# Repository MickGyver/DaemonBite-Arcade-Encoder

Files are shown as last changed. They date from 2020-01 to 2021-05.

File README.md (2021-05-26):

# DaemonBite-Arcade-Encoder
This is an arcade controller project for the MiSTer FPGA project and any other device accepting USB HID joysticks using an Arduino Pro Micro. This project can also be used to create a NeoGeo/Atari/Commodore/Amiga controller to USB adapters.

This project is an open source "lite" version of an arcade encoder I sell in my shop. If you want to support my work I sell the fully featured ones at https://daemonbite.com.

The input lag for an arcade controller or adapter built around this project is minimal. Here is the result from a test with a 1ms polling rate on a MiSTer with this project:

| Samples | Average | Max | Min | Std Dev |
| --- | --- | --- | --- | --- |
| 13962 | 0.74ms | 1.28ms | 0.23ms | 0.29ms |

## Wiring (Arcade Controller)
The wiring is simple. Connect one leg of each microswitch to GND and the other leg to the digital pin according to the schematic below. That's it!  
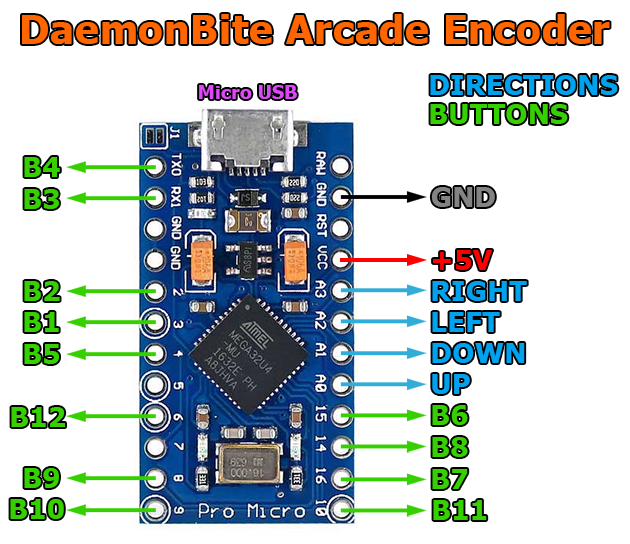
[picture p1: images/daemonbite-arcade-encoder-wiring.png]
Assemble1


## Recommended layout (for PS3 stick compatibility)
Blue text in image (silk screen) corresponds to the Bx button numbers in the image for wiring above. 
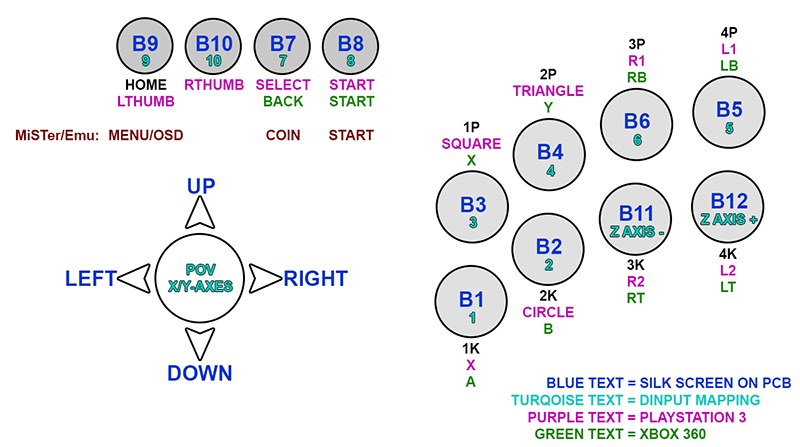
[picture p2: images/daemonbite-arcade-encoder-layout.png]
Assemble2


## Wiring (NeoGeo USB Adapter)
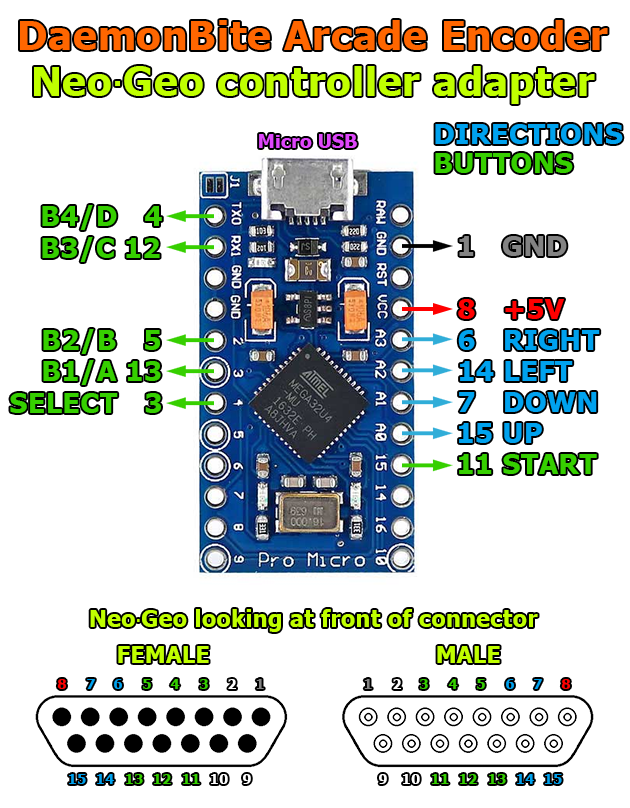
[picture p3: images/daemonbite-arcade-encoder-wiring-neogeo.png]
Assemble3


## Wiring (Atari/Commodore/Amiga USB Adapter)
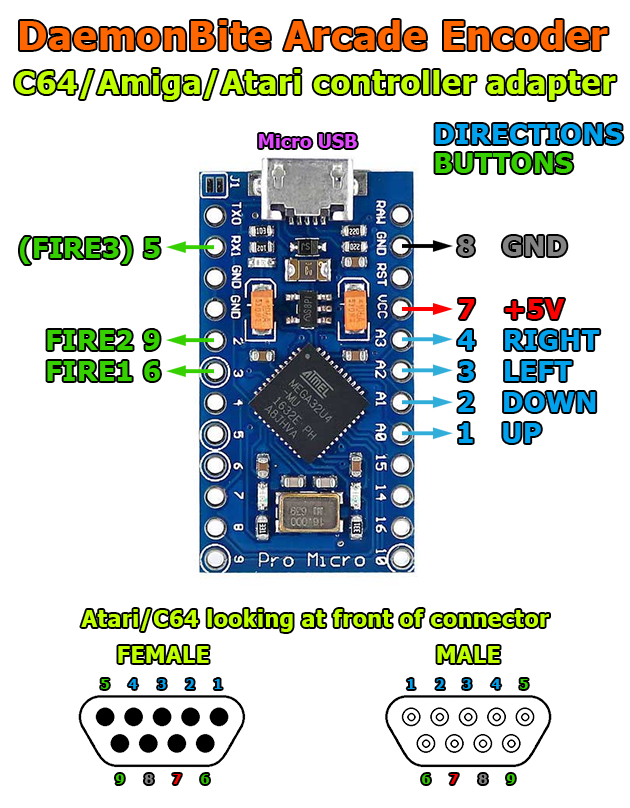
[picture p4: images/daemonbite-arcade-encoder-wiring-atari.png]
Assemble4


## Programming the Arduino
1. Download the free Arduino IDE: https://www.arduino.cc/en/main/software
2. Connect the Arduino Pro Micro to a USB port and let the drivers install.
3. Choose the correct board and virtual COM port in the IDE.
3. Compile/Upload the project.

## License
This project is licensed under the GNU General Public License v3.0. The name "daemonbite" is registered to my company in Finland and should not be used by others.

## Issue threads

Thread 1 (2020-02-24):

Support for multi-platform/universal wiring

mgolfieri, 2020-02-24:
It would be great to be able use the same platform wiring for all. Say you have the Arcade wiring, you can switch to control an Amiga or NeoGeo with the same setup, just by switching mapping in SW.  At the end of the day, GND and +V are going to be in the same spot, everything else should be doable as pure signals?

sorgelig, 2020-02-25:
From my point of view it's better to stick to the same adapter without jumping between different ones. Arduino Micro is dirt cheap, so just buy several boards and make adapters specific to different controllers and then update the FW only within the same adapter.
The project is targeted to simpliest way to build with minimum additional components. And this is a big advantage over universal adapters adjusting their pins to different controllers and require more complex wiring or even additional board.

MickGyver, 2020-02-26:
I agree with Sorgelig. Marcello, the adapters will work for various cores without rewiring anything, you can map the controller for each core in the menu on the MiSTer any way you want.

mgolfieri, 2020-02-26:
thank you both, makes sense.  Closing!

Closed 2020-02-26.

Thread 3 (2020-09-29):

Error compiling downloaded code

leeyanhuilyh, 2020-09-29:
Hi there. First of all, thank you for creating this project. My issue is that I am not able to compile the code. There are a lot of error messages here, so I think I might be missing some libraries. Here are the error messages:

In file included from C:\Users\metal\Desktop\DaemonBite-Arcade-Encoder\DaemonBiteArcadeEncoder\DaemonBiteArcadeEncoder.ino:24:0:
Gamepad.h:43:1: error: expected class-name before '{' token
 {
 ^
Gamepad.h:49:23: error: 'USBSetup' has not been declared
     int getDescriptor(USBSetup& setup);
                       ^~~~~~~~
Gamepad.h:51:16: error: 'USBSetup' has not been declared
     bool setup(USBSetup& setup);
                ^~~~~~~~
C:\Users\metal\Desktop\DaemonBite-Arcade-Encoder\DaemonBiteArcadeEncoder\DaemonBiteArcadeEncoder.ino: In function 'void setup()':
DaemonBiteArcadeEncoder:71:3: error: 'DDRF' was not declared in this scope
   DDRF  &= ~B11110000; // Set A0-A3 as inputs
   ^~~~
C:\Users\metal\Desktop\DaemonBite-Arcade-Encoder\DaemonBiteArcadeEncoder\DaemonBiteArcadeEncoder.ino:71:3: note: suggested alternative: 'WDRF'
   DDRF  &= ~B11110000; // Set A0-A3 as inputs
   ^~~~
   WDRF
DaemonBiteArcadeEncoder:72:3: error: 'PORTF' was not declared in this scope
   PORTF |=  B11110000; // Enable internal pull-up resistors
   ^~~~~
C:\Users\metal\Desktop\DaemonBite-Arcade-Encoder\DaemonBiteArcadeEncoder\DaemonBiteArcadeEncoder.ino:72:3: note: suggested alternative: 'PORT0'
   PORTF |=  B11110000; // Enable internal pull-up resistors
   ^~~~~
   PORT0
DaemonBiteArcadeEncoder:81:3: error: 'DDRE' was not declared in this scope
   DDRE  &= ~B01000000; // Pin 7 as input
   ^~~~
C:\Users\metal\Desktop\DaemonBite-Arcade-Encoder\DaemonBiteArcadeEncoder\DaemonBiteArcadeEncoder.ino:81:3: note: suggested alternative: 'DDRB'
   DDRE  &= ~B01000000; // Pin 7 as input
   ^~~~
   DDRB
DaemonBiteArcadeEncoder:82:3: error: 'PORTE' was not declared in this scope
   PORTE |=  B01000000; // Enable internal pull-up resistor
   ^~~~~
C:\Users\metal\Desktop\DaemonBite-Arcade-Encoder\DaemonBiteArcadeEncoder\DaemonBiteArcadeEncoder.ino:82:3: note: suggested alternative: 'PORT0'
   PORTE |=  B01000000; // Enable internal pull-up resistor
   ^~~~~
   PORT0
C:\Users\metal\Desktop\DaemonBite-Arcade-Encoder\DaemonBiteArcadeEncoder\DaemonBiteArcadeEncoder.ino: In function 'void loop()':
DaemonBiteArcadeEncoder:108:20: error: 'PINF' was not declared in this scope
     axesDirect = ~(PINF & B11110000);
                    ^~~~
In file included from sketch\Gamepad.cpp:26:0:
Gamepad.h:43:1: error: expected class-name before '{' token
 {
 ^
Gamepad.h:49:23: error: 'USBSetup' has not been declared
     int getDescriptor(USBSetup& setup);
                       ^~~~~~~~
C:\Users\metal\Desktop\DaemonBite-Arcade-Encoder\DaemonBiteArcadeEncoder\DaemonBiteArcadeEncoder.ino:108:20: note: suggested alternative: 'PIN0'
     axesDirect = ~(PINF & B11110000);
                    ^~~~
                    PIN0
Gamepad.h:51:16: error: 'USBSetup' has not been declared
     bool setup(USBSetup& setup);
                ^~~~~~~~
sketch\Gamepad.cpp: In constructor 'Gamepad_::Gamepad_()':
Gamepad.cpp:75:28: error: class 'Gamepad_' does not have any field named 'PluggableUSBModule'
 Gamepad_::Gamepad_(void) : PluggableUSBModule(1, 1, epType), protocol(HID_REPORT_PROTOCOL), idle(1)
                            ^~~~~~~~~~~~~~~~~~
Gamepad.cpp:75:71: error: 'HID_REPORT_PROTOCOL' was not declared in this scope
 Gamepad_::Gamepad_(void) : PluggableUSBModule(1, 1, epType), protocol(HID_REPORT_PROTOCOL), idle(1)
                                                                       ^~~~~~~~~~~~~~~~~~~
Gamepad.cpp:77:15: error: 'EP_TYPE_INTERRUPT_IN' was not declared in this scope
   epType[0] = EP_TYPE_INTERRUPT_IN;
               ^~~~~~~~~~~~~~~~~~~~
sketch\Gamepad.cpp:77:15: note: suggested alternative: 'EMPTY_INTERRUPT'
   epType[0] = EP_TYPE_INTERRUPT_IN;
               ^~~~~~~~~~~~~~~~~~~~
               EMPTY_INTERRUPT
Gamepad.cpp:78:3: error: 'PluggableUSB' was not declared in this scope
   PluggableUSB().plug(this);
   ^~~~~~~~~~~~
sketch\Gamepad.cpp: In member function 'int Gamepad_::getInterface(uint8_t*)':
Gamepad.cpp:84:3: error: 'HIDDescriptor' was not declared in this scope
   HIDDescriptor hidInterface = {
   ^~~~~~~~~~~~~
sketch\Gamepad.cpp:84:3: note: suggested alternative: 'getDescriptor'
   HIDDescriptor hidInterface = {
   ^~~~~~~~~~~~~
   getDescriptor
Gamepad.cpp:89:30: error: 'hidInterface' was not declared in this scope
   return USB_SendControl(0, &hidInterface, sizeof(hidInterface));
                              ^~~~~~~~~~~~
sketch\Gamepad.cpp:89:30: note: suggested alternative: 'getInterface'
   return USB_SendControl(0, &hidInterface, sizeof(hidInterface));
                              ^~~~~~~~~~~~
                              getInterface
Gamepad.cpp:89:10: error: 'USB_SendControl' was not declared in this scope
   return USB_SendControl(0, &hidInterface, sizeof(hidInterface));
          ^~~~~~~~~~~~~~~
sketch\Gamepad.cpp: At global scope:
Gamepad.cpp:92:29: error: 'int Gamepad_::getDescriptor' is not a static data member of 'class Gamepad_'
 int Gamepad_::getDescriptor(USBSetup& setup)
                             ^~~~~~~~
Gamepad.cpp:92:29: error: 'USBSetup' was not declared in this scope
sketch\Gamepad.cpp:92:29: note: suggested alternative: 'setup'
 int Gamepad_::getDescriptor(USBSetup& setup)
                             ^~~~~~~~
                             setup
Gamepad.cpp:108:22: error: 'bool Gamepad_::setup' is not a static data member of 'class Gamepad_'
 bool Gamepad_::setup(USBSetup& setup)
                      ^~~~~~~~
Gamepad.cpp:108:22: error: 'USBSetup' was not declared in this scope
sketch\Gamepad.cpp:108:22: note: suggested alternative: 'setup'
 bool Gamepad_::setup(USBSetup& setup)
                      ^~~~~~~~
                      setup
sketch\Gamepad.cpp: In member function 'void Gamepad_::send()':
Gamepad.cpp:159:12: error: 'pluggedEndpoint' was not declared in this scope
   USB_Send(pluggedEndpoint | TRANSFER_RELEASE, &_GamepadReport, sizeof(GamepadReport));
            ^~~~~~~~~~~~~~~
Gamepad.cpp:159:30: error: 'TRANSFER_RELEASE' was not declared in this scope
   USB_Send(pluggedEndpoint | TRANSFER_RELEASE, &_GamepadReport, sizeof(GamepadReport));
                              ^~~~~~~~~~~~~~~~
sketch\Gamepad.cpp:159:30: note: suggested alternative: '__ATOMIC_RELEASE'
   USB_Send(pluggedEndpoint | TRANSFER_RELEASE, &_GamepadReport, sizeof(GamepadReport));
                              ^~~~~~~~~~~~~~~~
                              __ATOMIC_RELEASE
Gamepad.cpp:159:3: error: 'USB_Send' was not declared in this scope
   USB_Send(pluggedEndpoint | TRANSFER_RELEASE, &_GamepadReport, sizeof(GamepadReport));
   ^~~~~~~~
sketch\Gamepad.cpp:159:3: note: suggested alternative: 'USBS0'
   USB_Send(pluggedEndpoint | TRANSFER_RELEASE, &_GamepadReport, sizeof(GamepadReport));
   ^~~~~~~~
   USBS0
sketch\Gamepad.cpp: In member function 'uint8_t Gamepad_::getShortName(char*)':
Gamepad.cpp:164:7: error: 'next' was not declared in this scope
   if(!next)
       ^~~~
sketch\Gamepad.cpp:164:7: note: suggested alternative: 'exit'
   if(!next)
       ^~~~
       exit
exit status 1
expected class-name before '{' token

Could someone shed some light on this issue?
Thanks.

vcoraba, 2020-11-14:
I had same problem but I could compile selecting Arduino Leonardo Instead arduino mini Pro. Good luck

0x15e, 2020-11-18:
The naming for the board this uses is really tricky. It's meant to be used with the "Arduino Pro Micro", which is a board made by Sparkfun ([this board](https://deskthority.net/wiki/Arduino_Pro_Micro)).

Unfortunately, over the years, there's also been about 100 other combinations of Arduino names including words like "pro," "mini," "micro," etc. so it gets really hard to tell the things apart. As you found, selecting the Leonardo gets the job done. I suspect that installing [Sparkfun's board files](https://github.com/sparkfun/Arduino_Boards) would probably get you the proper name for it in the list too, if that was important to you.

I remember being a little confused by this back when I put my adapters together as well. @MickGyver would it be possible to clarify the programming documentation a little? I think just some extra notes in the "Programming the Arduino" section would be enough. Just explain which board should be used and what it might be called in the IDE. I could probably do a PR for this but it might take a while before I can get around to it.

leeyanhuilyh, 2020-12-30:
Sorry for the late update. You guys are right, it should be compiled with Arduino Leonardo. Closing this issue. Thanks for your help!

Closed 2020-12-30.

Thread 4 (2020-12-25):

Changing the digital pin in case the board doesn't have enough

Gildedboy, 2020-12-25:
right now im trying to use the program and so far so good

sadly my arduino board (it's a Leonardo sold by a local electronic company) only have 13 digital pins instead of 16, so I'm unable to map out buttons B6-B7-B8, it is possible to change it so I can use another available pins?

the pin layout it's similar to this
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

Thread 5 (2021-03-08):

In emulationstation problem

Luciano2018, 2021-03-08:
Hi, thanks for this great code, is really fast, have a problem with the joystick, mine have switches instead of potenciometers, this maybe, cause that when choose console or game, step 4 consoles or games only pressing once the joystick, in the game works great, but can figureout how to fix it, try ps3 and neogeo option, the same issue

0x15e, 2021-03-08:
I had a similar problem with my build. Try looking in the source for the place where debounce is configured and enable it. That took care of my problem and didn't add any discernable lag.

Luciano2018, 2021-03-08:
Thanks for the quick help, i try your solution, hope too works🙏 cause the code its amazing.

Luciano2018, 2021-03-08:
Thank so much!!! Hours try different things and the answer already there hehe . For someone else with this Not an Issue, the simple solution is, in the sketch(DaemonBiteArcadeEncoder.ino), just change this line:
#define DEBOUNCE 0
to
#define DEBOUNCE 1

compile and upload just that, thanks again for the really fast help. Now i can play without lags and perfect in a pi 4, with pi os in retropie 4.7.9. Thanks!

juri74, 2021-04-01:
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

thanks but this will add 10ms of lag!

Luciano2018, 2021-04-01:
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

I dont have tools for measure delay, in real life isn't difference Jury, is working perfectly my joystick, i push all buttons without delay, and in the readme page of this code say that delay is max 1.28ms . I dont notice any change when change debounce to 1 , if in laboratory the delay change to 10ms i couldn't see any difference. By the way, zero delay board have 15ms of delay, so equally we have -5ms of delay with this code. In my particular case, i can play games with debounce 0, but in the menu emulationstation all go wrong, like if we push Re Pág in a text processor(the behaviour). So if you want the minimum delay posible(readme) just use the code like it is, with debounce 0, and navigate emulationstation with a keyboard or ir control, but if you want manage with your diy joystick at emulationstation then put debounce 1, is just a choice, in both case no visible delay in real world, if you notice it, maybe check your solder joints with a tester, checking a correct continuity, and dont put large cable, just the correct large for make the solder. You can see my tutorial with my diy joystick with this cool code if you google my name "Luciano Rabassa". Give it a try to this code, MickGyver make a great work!!!

MickGyver, 2021-04-01:
The debounce function will only add about 32µs of lag, not 10ms.
/MickGyver    On Thursday, April 1, 2021, 05:31:30 PM GMT+3, Raspberry Pi Buenos Aires ***@***.***> wrote:

Thank so much!!! Hours try different things and the answer already there hehe . For someone else with this Not an Issue, the simple solution is, in the sketch(DaemonBiteArcadeEncoder.ino), just change this line:
#define DEBOUNCE 0
to
#define DEBOUNCE 1
compile and upload just that, thanks again for the really fast help. Now i can play without lags and perfect in a pi 4, with pi os in retropie 4.7.9. Thanks!

thanks but this will add 10ms of lag!

I dont have tools for measure delay, in real life isn't difference Jury, is working perfectly my joystick, i push all buttons without delay, and in the readme page of this code say that delay is max 1.28ms . I dont notice any change when change debounce to 1 , if in laboratory the delay change to 10ms i couldn't see any difference. By the way, zero delay board have 15ms of delay, so equally we have -5ms of delay with this code. In my particular case, i can play games with debounce 0, but in the menu emulationstation all go wrong, like if we push Re Pág in a text processor(the behaviour). So if you want the minimum delay posible(readme) just use the code like it is, with debounce 0, and navigate emulationstation with a keyboard or ir control, but if you want manage with your diy joystick at emulationstation then put debounce 1, is just a choice, in both case no visible delay in real world, if you notice it, maybe check your solder joints with a tester, checking a correct continuity, and dont put large cable, just the correct large for make the solder. You can see my tutorial with my diy joystick with this cool code if you google my name "Luciano Rabassa". Give it a try to this code, MickGyver make a great work!!!

—
You are receiving this because you are subscribed to this thread.
Reply to this email directly, view it on GitHub, or unsubscribe.

Luciano2018, 2021-04-01:
Thanks for the real tech answer your code rocks 😎 Really thanks 👏👏👏

juri74, 2021-04-03:
Thank you! i read the 10ms on the code, 32µs is nothing :)

Closed 2021-03-08.

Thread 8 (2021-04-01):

Feature request

juri74, 2021-04-01:
Please, is it possible to use a standard arduino leonardo board, with the ability to use all available inputs?
So we could have 2 player controls, each one with 6 buttons + 3 other buttons (coin, 1p start and 2p start)
according to this sheet there are sufficient pins.
https://i.pinimg.com/originals/ac/cf/bb/accfbb18d1cea83169181a032a02b605.png
thanks

0x15e, 2021-04-01:
It has a 32u4 mcu so it should work fine (especially considering that when you program a pro micro, you still select Leonardo as the board type).

It should just be a matter of figuring out how the pins map, if they're even different at all. That should be easy enough to figure out by programming it and use some jumper wires to test which pins activate which functions. Start by using the same numbered pins as they're labeled in the diagram and if they don't match up, move on from there.

juri74, 2021-04-03:
too hard to do for my little knowledge :D
thank you anyway :)

kparlin, 2021-04-05:
Just spit balling here, but couldn't you wire two boards and assign player 1 to one and player 2 to the other? I have not tried it yet.

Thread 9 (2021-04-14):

Issues with old Neo Geo stick

0x15e, 2021-04-14:
I built one of these to use with my Neo Geo controllers (some CD pads as well as an old-style home stick).

It works beautifully with the CD pads but there's something really weird going on with the stick.

On the stick, if I hold Start long enough, it triggers Select as well (or maybe it's Select triggering Start, I don't have it in front of me right now). It also happens if I rapidly press the button enough times. It's like the presses have a cumulative effect (which makes no sense because all the buttons do is short a pin to ground in the old home sticks.

Holding the other button doesn't have the same effect and all other directions and buttons are working properly, and like I said, the CD pads work perfectly.

Is there something known weird about the old sticks? Or could there be a way to modify my stick to make it more reliable (decoupling caps, a buffer, etc.)? It's not like I go around holding the Start (or Select) button but it would be nice to not have to worry about accidentally triggering the MiSTer or Universe Bios menus.

Closed 2021-04-28.

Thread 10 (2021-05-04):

"menu ok" action : impossible to assign

robinmasters2, 2021-05-04:
hello,
I've just setup an arduino pro micro and loaded it with the arcade encoder software.
I use it on mister.

The issue I'm having  is that, when assigning the buttons for the mister menu, a double clic is happening when assigning the "menu ok" action. in consequence It also assigns the "menu back" action on the same button.

it's only happening is this particular situation.
in game no double click.
it happens whathever the button is.

after sharing with friends, looks like two of my pals are expériencing the same issue.
is there already a workaround ?

thank you.

0x15e, 2021-05-05:
You need to enable debounce in the source and reflash your Arduino. It should be as simple as uncommenting one line.

robinmasters2, 2021-05-05:
thank you it worked !

Closed 2021-05-05.

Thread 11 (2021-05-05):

How do you measure input delay?

nebhead, 2021-05-05:
Not an issue, just curious how you are measuring input delay on this project.  I'd put together my own arcade stick example a couple of years back ([link to the commit here](https://github.com/nebhead/ArduinoJoystickLibrary/commit/2263e785853077b965f86cb6ac096e8d8c8b6f31)) as a fork of someone else's project and I'd like to know how well it works compared to this one.  Yours looks much cleaner and I may consider switching over.  (also, expect some traffic here as someone has posted a video using your project to Reddit - consider setting up discussions on this repository)  Nice work!

0x15e, 2021-05-05:
I'm 99% sure he's using Porkshop's MiSTer latency tester core / procedure. You can find more info about the procedure and aggregated results here (check all the different sheets for the results): https://docs.google.com/spreadsheets/d/1KlRObr3Be4zLch7Zyqg6qCJzGuhyGmXaOIUrpfncXIM/edit#gid=369482991

I tried some other Arduino / STM32 firmwares (including Freejoy but not sure if I tried the one you linked) and DaemonBite was so much faster than everything it wasn't even funny.

Especially impressive is the way debounce is implemented. Without debounce, many arcade controls such as the IL Eurostick and Happ buttons will trigger multiple times per activation so you really need it in the arcade adapter. When I tested Freejoy, whatever time you configure for debounce was basically added to the input latency ... so like 15-20ms. It was nuts. DaemonBite does it differently so that enabling debounce is practically free (it still adds a super tiny time to latency but it's negligible).

nebhead, 2021-05-05:
Outstanding, thanks for the response.  This is very comprehensive data.  I'm relatively positive daemonbite is better than the code I linked above because my debounce is 10ms at a minimum.

Well, looks like I'm going to have a fun weekend project to do on my arcade. :)  Honestly though, it should be really simple to get this implemented with my current setup so I'm excited to give it a go.

MickGyver, 2021-05-06:
> Especially impressive is the way debounce is implemented. Without debounce, many arcade controls such as the IL Eurostick and Happ buttons will trigger multiple times per activation so you really need it in the arcade adapter. When I tested Freejoy, whatever time you configure for debounce was basically added to the input latency ... so like 15-20ms. It was nuts. DaemonBite does it differently so that enabling debounce is practically free (it still adds a super tiny time to latency but it's negligible).

I'm quite proud of my debounce logic, I haven't seen it anywhere else, usually debouncing adds a lot of lag. My way of doing it is ignoring button changes for 10ms after a change has occured, this means that a button can't change state more often than 10ms but it is basically physically impossible to do that anyway.

nebhead, 2021-05-06:
@MickGyver - You should be proud. :)  It does work really well and is definitely an upgrade over the code that I was using before.  I wasn't planning on updating my arcade cabinet until the weekend, but I got a little too excited and stayed up late last night to get it working.  It worked flawlessly, first time, and is very responsive.  Even the X-Y is much more responsive than my previous implementation.  Well done!

I wanted to mention that I also followed the guidance at the end of this video: https://www.youtube.com/watch?v=hoCOq9Ngp44 (@19:17), to rename the USB devices to 'DaemonBite (Player 1)' and 'DaemonBite (Player 2)'.  This is extremely useful for my setup in the cabinet where it's hard to discern between the different controllers, especially when it's all closed up.  Hopefully that helps someone else here.

Closed 2021-05-05.

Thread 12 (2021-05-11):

Compile Error in Gamepad.h

Lazyace1980, 2021-05-11:
error expected class-name before '{' token

nebhead, 2021-05-26:
Usually that means you don't have the correct board selected in the board manager (i.e. pro-micro or leonardo).

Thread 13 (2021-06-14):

[FR] switchable Xinput mode

eadmaster, 2021-06-14:
not sure if doable, btw some commercial controllers allow you to switch from XInput<->DInput mode for better compatibility with newer/older games.

Another reason to switch back to DInput is to have [lower latencies as suggested here](https://github.com/dmadison/ArduinoXInput/issues/49#issuecomment-787410909).

sigboe, 2021-06-15:
The Daemonbite arcade encoder has an average latency of 0.758 ms, with standard deviation of 0.289. In a 60fps game this gives a same frame probability of 95.45% This is tested by Porkchop Express from https://misteraddons.com (input latency in the top menu as source)

I dont think there is anything to get from switching to dinput, but have you looked at this line? https://github.com/MickGyver/DaemonBite-Arcade-Encoder/blob/master/DaemonBiteArcadeEncoder/DaemonBiteArcadeEncoder.ino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

Closed 2022-12-30.

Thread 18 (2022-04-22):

Fire2 + C64 joystick + VCC

mistepien, 2022-04-22:
According to that documentation:
http://wiki.icomp.de/wiki/DE-9_Joystick#2.2F3_Button_modification
http://wiki.icomp.de/wiki/File:JoystickMod.jpg

to have FIRE2 with C64 the pin 9 has to be pulled to VCC.
Right now FIRE2 works with DBAE only if that is pulled to GND -- just like in Amiga, but that will not work for C64.

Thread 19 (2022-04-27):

Problem on Windows

NuClear235, 2022-04-27:
This device is on Windows PC shown as Arduino Micro and not as joystick and is not working.
I need to have it shown as joystick or gamepad device with possibility of setting and testing...
On Mister is it working fine.

0x15e, 2022-04-27:
I think it does show up in Device Manager as Arduino Micro but it should be working as a class-compliant game controller. Are you saying you've checked the "Set up USB game controllers" control panel and it's not in there?

0x15e, 2022-04-27:
I just connected mine and confirmed. There should be two devices for it in Device Manager: a COM port called "Arduino Micro (COM?)" and "HID-compliant game controller" under "Human Interface Devices."

For mine, it shows up in "Set up USB game controllers" as "Arduino Leonardo" with 3 axes, POV hat, and 12 buttons.

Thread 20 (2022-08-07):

Compilation error: redefinition of 'class Gamepad_' - how to fix

alamone, 2022-08-07:
Get this error when compiling after installing HID-Project library.
To fix it, need to comment out the following in "documents/Arduino/libraries/HID-Project/src/HID-project.h"

#include "MultiReport/Gamepad.h"

e.g. to:
// #include "MultiReport/Gamepad.h"

Then I was able to compile successfully.  Not sure if this is a changed behavior of Arduino IDE regarding priority of duplicate includes.  This behavior happened on Arduino IDE 1.8.19 and 2.0.0-rc9.1.

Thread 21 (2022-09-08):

Debounce (?) issues in Steam

davewongillies, 2022-09-08:
I'm not entirely sure what's going on, but the Daemonbite will continually trigger down after pressing up on the controller while in Steam's controller configuration, and also when using it in the Steam UI (on both Linux & SteamOS which is just Linux anyhow) & any games launched from Steam. Using the joystick outside of Steam is fine, so there's obviously something funky about the controller layer with Steam.

I found [this thread on reddit](https://www.reddit.com/r/fightsticks/comments/pw0qjw/problems_with_daemonbite_arduino_on_steam/) which claims that enabling `DEBOUNCE` fixes this, but I've had no success. I've also tried changing the value for `DEBOUNCE_TIME` up to `50` too but its made no difference so far.

davewongillies, 2022-09-08:
I just tried enabling `PS3` mode and direction buttons work, but now R2 seems to be triggering repeated presses

davewongillies, 2022-10-01:
I ended up with this franken setup https://github.com/davewongillies/DaemonBite-Arcade-Encoder/commit/427979cf7c62e4085b15cfa27bcb8c0e94508c20 where I have PS3 joystick mode, but keep the normal B11/B12 buttons. I also had to bump `DEBOUNCE_TIME` up to `100` (I tried `50` to no avail, but just jumped to `100` so perhaps something in between works).

```diff
--- a/DaemonBiteArcadeEncoder/DaemonBiteArcadeEncoder.ino
+++ b/DaemonBiteArcadeEncoder/DaemonBiteArcadeEncoder.ino
@@ -23,11 +23,12 @@

 #include "Gamepad.h"

-//#define PS3                 // PS3 (ScpToolkit) compatibility (Comment out for joystick=X/Y-Axis and B11/B12 as normal buttons)
+#define PS3                 // PS3 joystick (ScpToolkit) compatibility (Comment out for joystick=X/Y-Axis)
+//#define PS3_BUTTONS       // PS3 button (ScpToolkit) compatibility (B11/B12 as normal buttons)
 //#define NEOGEO

-#define DEBOUNCE 0          // 1=Diddly-squat-Delay-Debouncing™ activated, 0=Debounce deactivated
-#define DEBOUNCE_TIME 10    // Debounce time in milliseconds
+#define DEBOUNCE 1          // 1=Diddly-squat-Delay-Debouncing™ activated, 0=Debounce deactivated
+#define DEBOUNCE_TIME 100   // Debounce time in milliseconds
 //#define DEBUG             // Enables debugging (sends debug data to usb serial)

 #ifdef NEOGEO
@@ -167,7 +168,7 @@ void loop()
     // Has button inputs changed?
     if(buttons != buttonsPrev)
     {
-      #ifdef PS3
+      #ifdef PS3_BUTTONS
         Gamepad._GamepadReport.buttons = buttons & 0x3FF;
         if(buttons & 0x400) // B11
           Gamepad._GamepadReport.Z = -1;
```

Perhaps this may be of help to someone else facing the same issue with Steam, but I'll be closing this issue as I've moved my joystick to another project. Thanks.

Closed 2022-10-01.

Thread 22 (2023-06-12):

Not recognised in games as a controller

cRazi-man, 2023-06-12:
I'm having trouble with getting this working. I've uploaded to the Arduino Pro micro and Windows recognises it as a game controller. It recognises all the button presses. But Steam can't see it as a controller and games don't recognise the controller. It is not showing up as an XInput device. Any advice on how to resolve this?

I'm new to Arduino so need things a bit dumbed down please.
Thanks

SrBroccoli, 2024-05-01:
I know this issue was posted a long time ago, but I was having the same issue as found a fix.

Just go to the Steam settings > controllers

from there, I activated “generic controller entry” or something like that, and steam detected the controller as “Arduino Leonardo Controller”, after that I had to map the controls to the Arduino inputs and it all worked as expected.

regiregi22, 2024-12-20:
> I'm having trouble with getting this working. I've uploaded to the Arduino Pro micro and Windows recognises it as a game controller. It recognises all the button presses. But Steam can't see it as a controller and games don't recognise the controller. It is not showing up as an XInput device. Any advice on how to resolve this?
>
> I'm new to Arduino so need things a bit dumbed down please. Thanks

That's because, in fact, it is not an XInput device.

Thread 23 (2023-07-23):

rgb-pi not working on every advancemame game

ruicunhaa, 2023-07-23:
Have rgb-pi connected to a crt, encoder works great on fbneo, but when i switch to advancemame ganes encoder doesnt work.

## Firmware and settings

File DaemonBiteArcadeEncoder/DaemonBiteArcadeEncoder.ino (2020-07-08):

/*  DaemonBite Arcade Encoder
 *  Author: Mikael Norrgård <mick@daemonbite.com>
 *
 *  Copyright (c) 2020 Mikael Norrgård <http://daemonbite.com>
 *  
 *  GNU GENERAL PUBLIC LICENSE
 *  Version 3, 29 June 2007
 *  
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
 */

#include "Gamepad.h"

//#define PS3                 // PS3 (ScpToolkit) compatibility (Comment out for joystick=X/Y-Axis and B11/B12 as normal buttons)
//#define NEOGEO

#define DEBOUNCE 0          // 1=Diddly-squat-Delay-Debouncing™ activated, 0=Debounce deactivated
#define DEBOUNCE_TIME 10    // Debounce time in milliseconds
//#define DEBUG             // Enables debugging (sends debug data to usb serial)

#ifdef NEOGEO
  const char *gp_serial = "NeoGeo to USB";
#else
  const char *gp_serial = "Daemonbite Arcade";
#endif

#define UP    0x80
#define DOWN  0x40
#define LEFT  0x20
#define RIGHT 0x10

Gamepad_ Gamepad;           // Set up USB HID gamepad
bool usbUpdate = false;     // Should gamepad data be sent to USB?
bool debounce = DEBOUNCE;   // Debounce?
uint8_t  pin;               // Used in for loops
uint32_t millisNow = 0;     // Used for Diddly-squat-Delay-Debouncing™


uint8_t  axesDirect = 0x0f;
uint8_t  axes = 0x0f;
uint8_t  axesPrev = 0x0f;
uint8_t  axesBits[4] = {0x10,0x20,0x40,0x80};
uint32_t axesMillis[4];

uint16_t buttonsDirect = 0;
uint16_t buttons = 0;
uint16_t buttonsPrev = 0;
uint16_t buttonsBits[12] = {0x01,0x02,0x04,0x08,0x10,0x20,0x40,0x80,0x100,0x200,0x400,0x800};
uint32_t buttonsMillis[12];

#ifdef DEBUG
  char buf[16];
  uint32_t millisSent = 0;
#endif

void setup() 
{
  // Axes
  DDRF  &= ~B11110000; // Set A0-A3 as inputs
  PORTF |=  B11110000; // Enable internal pull-up resistors

  // Buttons
  DDRD  &= ~B10011111; // Set PD0-PD4 and PD7 as inputs
  PORTD |=  B10011111; // Enable internal pull-up resistors
  DDRB  &= ~B01111110; // Set PB1-PB6 as inputs
  PORTB |=  B01111110; // Enable internal pull-up resistors

  // Debounce selector switch (currently disabled)
  DDRE  &= ~B01000000; // Pin 7 as input
  PORTE |=  B01000000; // Enable internal pull-up resistor

  // Initialize debouncing timestamps
  for(pin=0; pin<4; pin++)
    axesMillis[pin]=0;
  for(pin=0; pin<12; pin++)   
    buttonsMillis[pin]=0;

  Gamepad.reset();

  #ifdef DEBUG
    Serial.begin(115200);
  #endif
}

void loop() 
{
  // Get current time, the millis() function should take about 2µs to complete
  millisNow = millis();

  // Check debounce selector switch
  // debounce = (PINE & B01000000) ? false : true;

  for(uint8_t i=0; i<10; i++) // One iteration (when debounce is enabled) takes approximately 35µs to complete, so we don't need to check the time between every iteration
  {
    // Read axis and button inputs (bitwise NOT results in a 1 when button/axis pressed)
    axesDirect = ~(PINF & B11110000);
    buttonsDirect = ~((PIND & B00011111) | ((PIND & B10000000) << 4) | ((PINB & B01111110) << 4));

    if(debounce)
    {
      // Debounce axes
      for(pin=0; pin<4; pin++)
      {
        // Check if the current pin state is different to the stored state and that enough time has passed since last change
        if((axesDirect & axesBits[pin]) != (axes & axesBits[pin]) && (millisNow - axesMillis[pin]) > DEBOUNCE_TIME)
        {
          // Toggle the pin, we can safely do this because we know the current state is different to the stored state
          axes ^= axesBits[pin];
          // Update the timestamp for the pin
          axesMillis[pin] = millisNow;
        }
      }
      
      // Debounce buttons
      for(pin=0; pin<12; pin++)
      {
        // Check if the current pin state is different to the stored state and that enough time has passed since last change
        if((buttonsDirect & buttonsBits[pin]) != (buttons & buttonsBits[pin]) && (millisNow - buttonsMillis[pin]) > DEBOUNCE_TIME)
        {
          // Toggle the pin, we can safely do this because we know the current state is different to the stored state
          buttons ^= buttonsBits[pin];
          // Update the timestamp for the pin
          buttonsMillis[pin] = millisNow;
        }
      }
    }
    else
    {
      axes = axesDirect;
      buttons = buttonsDirect;
    }
  
    // Has axis inputs changed?
    if(axes != axesPrev)
    {
      #ifdef PS3
        Gamepad._GamepadReport.hat = dpad2hat(axes);
      #else
        // UP + DOWN = UP, SOCD (Simultaneous Opposite Cardinal Directions) Cleaner
        if(axes & B10000000)
          Gamepad._GamepadReport.Y = -1;
        else if(axes & B01000000)
          Gamepad._GamepadReport.Y = 1;
        else
          Gamepad._GamepadReport.Y = 0;
        // UP + DOWN = NEUTRAL
        //Gamepad._GamepadReport.Y = ((axes & B01000000)>>6) - ((axes & B10000000)>>7);
        // LEFT + RIGHT = NEUTRAL
        Gamepad._GamepadReport.X = ((axes & B00010000)>>4) - ((axes & B00100000)>>5);
      #endif
      axesPrev = axes;
      usbUpdate = true;
    }
  
    // Has button inputs changed?
    if(buttons != buttonsPrev)
    {
      #ifdef PS3
        Gamepad._GamepadReport.buttons = buttons & 0x3FF;
        if(buttons & 0x400) // B11
          Gamepad._GamepadReport.Z = -1;
        else if(buttons & 0x800) // B12
          Gamepad._GamepadReport.Z = 1;
        else
          Gamepad._GamepadReport.Z = 0;
      #else
        Gamepad._GamepadReport.buttons = buttons;
      #endif

      buttonsPrev = buttons;
      usbUpdate = true;
    }
  
    // Should gamepad data be sent to USB?
    if(usbUpdate)
    {
      Gamepad.send();
      usbUpdate = false;

      #ifdef DEBUG
        sprintf(buf, "%06lu: %d%d%d%d", millisNow-millisSent, ((axes & 0x10)>>4), ((axes & 0x20)>>5), ((axes & 0x40)>>6), ((axes & 0x80)>>7) );
        Serial.print(buf);
        sprintf(buf, " %d%d%d%d", (buttons & 0x01), ((buttons & 0x02)>>1), ((buttons & 0x04)>>2), ((buttons & 0x08)>>3) );
        Serial.println(buf);
        millisSent = millisNow;
      #endif
    }
  }
}

uint8_t dpad2hat(uint8_t dpad)
{
  switch(dpad & (UP|DOWN|LEFT|RIGHT))
  {
    case UP:         return 0;
    case UP|RIGHT:   return 1;
    case RIGHT:      return 2;
    case DOWN|RIGHT: return 3;
    case DOWN:       return 4;
    case DOWN|LEFT:  return 5;
    case LEFT:       return 6;
    case UP|LEFT:    return 7;
  }
  return 15;
}

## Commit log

2019-10-21 Support for up to 12 buttons
2020-01-28 Fixed bug with buttons 9-12
    [DaemonBiteArcadeEncoder.ino]
2020-02-16 Changed START pin mapping for NeoGeo
2020-03-13 Fixed a for-loop bug.
    [DaemonBiteArcadeEncoder.ino]
2020-05-11 Fixed a small bug
    [DaemonBiteArcadeEncoder.ino]
2020-07-08 Wiring image updated

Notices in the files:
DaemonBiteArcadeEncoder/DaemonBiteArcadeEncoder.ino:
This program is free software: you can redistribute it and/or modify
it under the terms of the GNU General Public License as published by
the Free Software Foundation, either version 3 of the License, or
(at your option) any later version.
